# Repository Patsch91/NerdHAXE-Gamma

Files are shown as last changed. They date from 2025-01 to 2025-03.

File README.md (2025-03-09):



**The NerdHaxe-Gamma is a 6-Asic-Miner based on the [NerdQAxe+(+)](https://github.com/shufps/qaxe) / [Nerdaxe](https://github.com/BitMaker-hub/NerdAxeUltra) and inspired by [OSMU](https://osmu.wiki/) and the [Bitaxe](https://github.com/bitaxeorg)**

Current status: First version is running pretty solid. Disclaimer: This is a hobby project and not a professional or commercial product so feel free to build / make changes and share ideas on how to improve the design

 

# Specifications
- **Open Source:** All design files are provided, and suggestions/improvements are always welcome.
- **Standalone:** Using the T-Display S3 with WiFi and works without an external controller.
- **Performance:** ~7.35 TH/s average at around 120-125 watts (measured at the wall, including a MW UHP-200-12).
- **Case:** DIY Idea for a 3D-printed case with an integrated PSU.

# Software / Firmware
The NerdHaxe-Gamma uses the [ESP-Miner](https://github.com/shufps/ESP-Miner-NerdQAxePlus) by shufps and the [Webflasher](https://shufps.github.io/nerdqaxe-web-flasher/) is recommended as the easiest way to flash the NerdHaxe-Gamma (or any other Nerd*axe variant). It uses the official releases and is always up to date.
<br> The screen displays key values and parameters, such as the current hashrate, session runtime, fan speed, and more.
<br><br> 
<br> Via your browser, you can monitor all important aspects, such as the hashrate graph, adjust settings like core voltage and fan speed, define a fallback stratum pool, or simply check the logs.
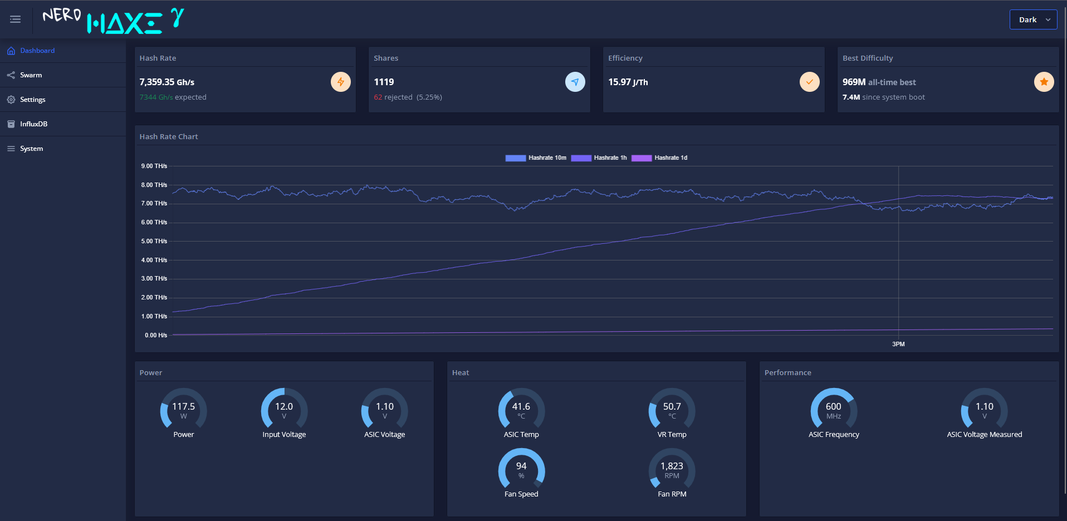
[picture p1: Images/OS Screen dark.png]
<br><br> 

# Components
- **Asics:** 6 x BM1370
- **T-Display S3:** ESP32S3 microcontroller with WiFi and integrated display
- **PCB:** I ordered the prototype PCB as specified in the KiCad files above, with a copper thickness of 1/1 oz, and it has been running well so far. One thing I tried on this PCB was exposing the pads underneath the ASICs to improve thermal connection to the backside of the PCB, where 10x10mm heatsinks can be placed.
- **BOM:** The board components needed for the build can be found in the BOM.
- **Heatsink:** The PCB has slotted holes that accommodate mounting patterns from 75x75mm to 80x80mm. The mounting patterns fit some LGA15xx or 2011 coolers, but be mindful of the thermal contact area of the coolers you want to use. Most standard coolers have a contact area of around 40x40mm, which is not sufficient. Therefore, I used server heatsinks such as the Supermicro SNK-P0048P(W) with a completely flat contact surface.
- **Fans:** Currently, I am using 2x Noctua A9x25 PWM chromax fans in a push-pull configuration, and at 75-85% PWM, the sound level is quite ok. I will soon test the Arctic P9 Max model, which is more powerful than the Noctuas, but of course, at a higher noise level.
- **PSU:** The NerdHaxe-Gamma operates at around 12V and 10A with default settings. Therefore, I recommend using a PSU that provides 12V and at least 15A. I am using the Meanwell UHP-200-12. <br>

# Misc 
**DISCLAIMER:** This device is an *advanced* build and partly WIP. To get 6 Asics soldered properly *can* be very hard and frustrating if you are not used to soldering Asics or soldering in general. Using that amount of power, this device is not a toy, and you should know what you are doing. Follow the regulations and precautions – **stay safe!** <br>

If you like this project and want to support future work, feel free to donate to: **`bc1q0ctaxeha3lpsaaz7kpjulflw2d9p66fhkp48dk`**

or related projects without which this project would not have been possible for me:

[NerdQAxe+](https://github.com/shufps/qaxe)

[OSMU](https://osmu.wiki/)

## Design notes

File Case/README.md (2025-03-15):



# Case 
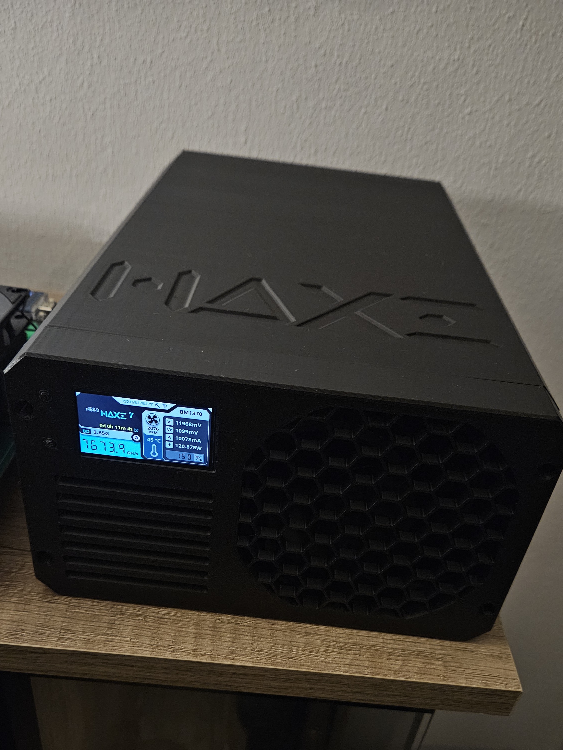
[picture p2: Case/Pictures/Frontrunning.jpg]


- **3D-printed parts:** You can find the files in here 
- **M3 inserts:** I used threaded nuts (M3) to hold the parts together 
- **PEM:** Power entry module with fuse and switch to cut the power without pulling any other connections. Please know what you are doing ad follow the regulations/rules as this is connected to AC.
- **Screws:** this design is made for M3 screws 
- **Fans:** I am using 2x Noctua A9x25 PWM chromax fans in a push-pull configuration, and at 80% PWM, the sound level is quite pleasant. The Arctic P9 Max are working very well with much headroom but at a higher noise level
- **PSU:** Meanwell UHP-200-12. <br>

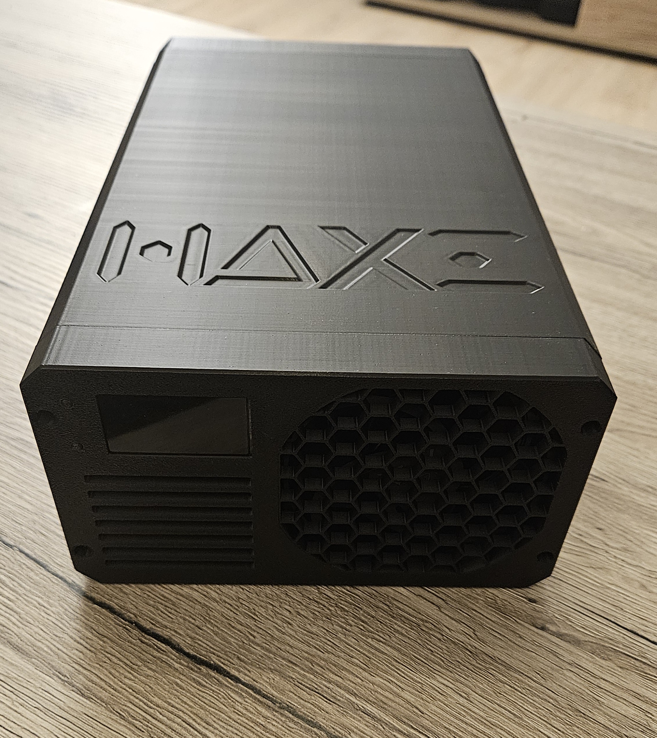
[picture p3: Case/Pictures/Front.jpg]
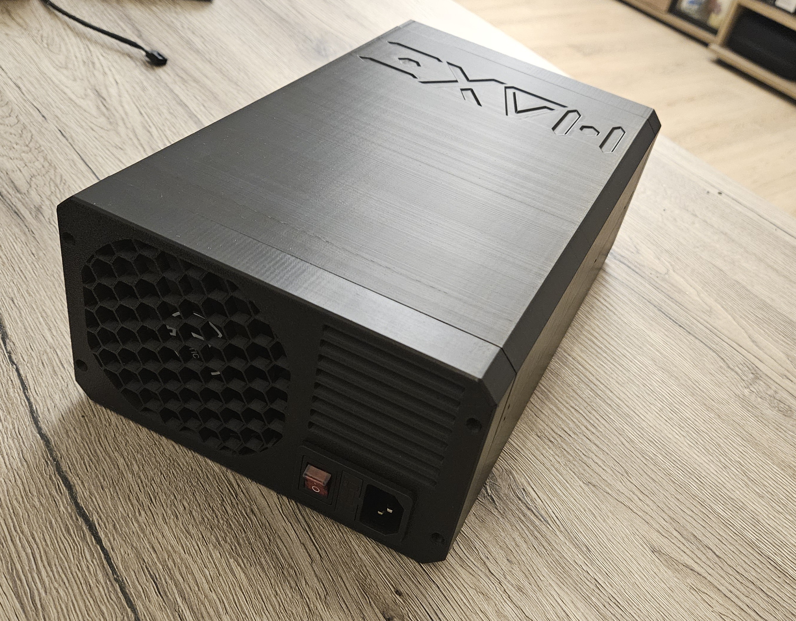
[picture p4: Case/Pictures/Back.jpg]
  

# Misc 
**DISCLAIMER:** This device is an *advanced* build and partly WIP. To get 6 Asics soldered properly *can* be very hard and frustrating if you are not used to soldering Asics or soldering in general. Using that amount of power, this device is not a toy, and you should know what you are doing. Follow the regulations and precautions – **stay safe!** <br>

If you like this project and want to support future work, feel free to donate to: **`bc1q0ctaxeha3lpsaaz7kpjulflw2d9p66fhkp48dk`**

or related projects without which this project would not have been possible for me:

[NerdQAxe+](https://github.com/shufps/qaxe)

[OSMU](https://osmu.wiki/)

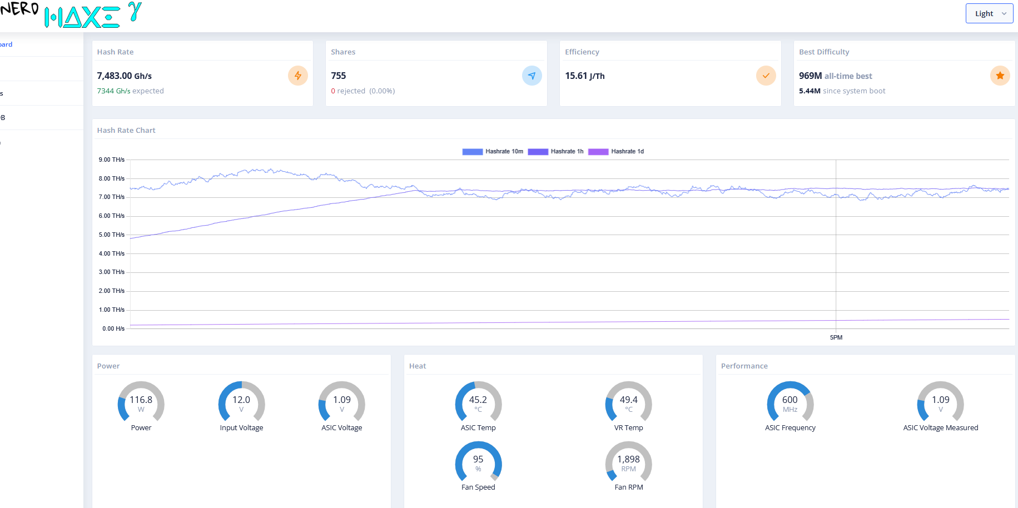
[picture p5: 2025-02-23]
Images/OS Screenshot light.png

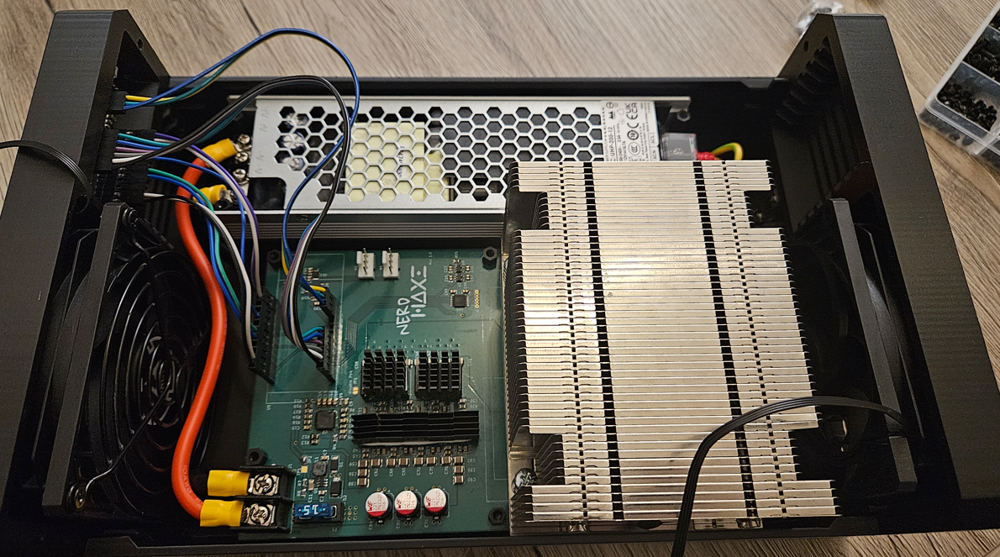
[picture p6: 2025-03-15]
Case/Pictures/Inside.png

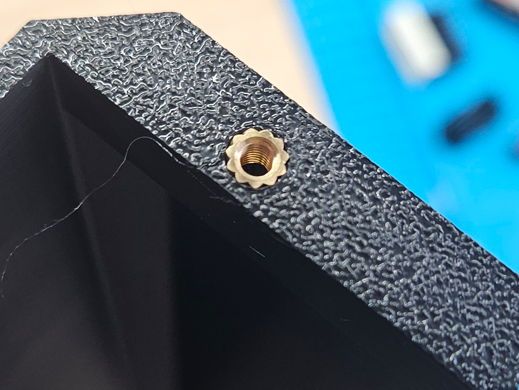
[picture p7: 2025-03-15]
Case/Pictures/Insert.png

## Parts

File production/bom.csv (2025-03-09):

Designator | Footprint | Quantity | Value | LCSC Part #
C1 | 0805 | 1 | 2.2n
C10 | 0805 | 1 | 330n
C100, C115, C127, C143, C159, C16, C175, C18, C19, C191, C20, C21, C23, C27, C28, C29, C30, C93, C94, C95, C96, C97, C98, C99 | 0805 | 24 | 100n/0.7mm
C101, C102, C103, C104, C105, C106, C107, C108, C109, C110, C111, C112, C114, C117, C118, C119, C12, C120, C121, C123, C125, C126, C128, C129, C130, C131, C132, C133, C134, C135, C136, C137, C139, C14, C141, C142, C144, C145, C146, C147, C148, C149, C150, C151, C152, C153, C155, C157, C158, C160, C161, C162, C163, C164, C165, C166, C167, C168, C169, C17, C171, C173, C174, C176, C177, C178, C179, C180, C181, C182, C183, C184, C185, C187, C189, C190, C192, C193, C194, C195, C196, C31, C43, C51, C57, C64 | 0805 | 86 | 1µ/25V
C11 | 1206 | 1 | 22µ/16V
C113, C122, C138, C154, C170, C186, C2, C41, C44, C46, C50 | 0805 | 11 | 10µ/25V
C116, C124, C140, C156, C172, C188, C42, C45, C48, C49, C52, C53, C55, C58 | 1210 | 14 | 100µ/6.3V
C13 | 0805 | 1 | 4.7µ
C15, C32, C33, C34, C35, C36, C37, C38, C39, C6, C9 | 0805 | 11 | 1n/0.7mm
C22, C24, C25, C26 | 0805 | 4 | 2.2µ
C3, C4, C5 | 0603 | 3 | 22p
C40, C47, C54, C61 | 0805 | 4 | 3.3n/25V
C56, C59, C62, C66, C69, C72, C75, C78, C82, C85, C88, C90 | 1210 | 12 | 22µ/25V
C60, C63, C65, C67, C68, C70, C71, C73, C74, C77, C79, C81, C83, C86, C87, C89, C91, C92 | 1210 | 18 | 330µ/4V
C7 | 0805 | 1 | 10n
C76, C80, C84 | CP_Elec_8x10 | 3 | 220µ/25V
C8 | 0603 | 1 | 12p
D1 | D_SOD-128 | 1 | PMEG4030EP,115
D2 | D_SMB | 1 | SMBJ12A
D3 | D_SOD-123 | 1 | 1N5819
F1 | Fuseholder Blade_3568 | 1 | 3568
J1 | CONN2 | 1 | Connector 02x01
L1 | L_Taiyo-Yuden_NR-50xx | 1 | 4.7µH/2.3A/2.7A
L2, L3, L4, L5 | IFLR-4031GC-01-8x10 | 4 | 220nH
M1, M2 | FanPinHeader_1x04_P2.54mm_Vertical | 2 | Fan_4pin
R1 | 0805 | 1 | 49.9k
R10, R11 | 0805 | 2 | 2.2R/0.5W
R12 | 0805 | 1 | 16.5k
R13 | 0805 | 1 | 24.3k
R14, R15, R16, R27, R31, R34, R37, R40, R43, R46, R48 | 0805 | 11 | 10k
R17, R18, R19, R20, R21, R22, R23, R24 | 0805 | 8 | 1R/0.5W
R2, R3 | 0805 | 2 | 100
R25, R26, R32, R35 | 0805 | 4 | 0
R28, R29 | 0805 | 2 | 2.7k
R30, R33, R36, R39, R42, R45 | 0805 | 6 | 1k
R4 | 0805 | 1 | 100k
R5 | 0805 | 1 | 121k
R6 | 0805 | 1 | 8.06k
R7 | 0805 | 1 | 84.5k
R8 | 0805 | 1 | 16.2k
R9 | 0805 | 1 | 2.55k
U1 | SOT-23-6 | 1 | AP3211
U10 | MSOP-10_3x3mm_P0.5mm | 1 | EMC2302-1
U11 | VSSOP-8_2.3x2mm_P0.5mm | 1 | TXU0102-DCU
U12, U13 | TMP1075-DRL | 2 | TMP1075
U14 | TSSOP-14-1EP_4.4x5mm_P0.65mm | 1 | TXU0304PW
U15 | Oscillator_SMD_EuroQuartz_XO32-4Pin_3.2x2.5mm | 1 | 25MHz
U16, U17, U18, U19, U20, U21 | BM1370 | 6 | BM1370_mode1
U2 | Texas_RHA0040B_VQFN-40-1EP_6x6mm_P0.5mm_EP4.15x4.15mm_ThermalVias | 1 | TPS53647
U3 | SOT-23-5 | 1 | MCP1824T-0802E
U4, U5, U6, U7 | CSD95472-SON-5x6 | 4 | CSD95472Q5MC
U8 | SOT-23-5 | 1 | MCP1824T-1202E

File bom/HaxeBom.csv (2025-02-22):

Reference | Value | Footprint | OrderNr | Qty | DNP | Distributor
C1 | 2.2n | Capacitor_SMD:C_0805_2012Metric | 1276-2993-1-ND | 1 |  | D
C2,C41,C44,C46,C50,C113,C122,C138,C154,C170,C186 | 10µ/25V | Capacitor_SMD:C_0805_2012Metric | 445-5984-1-ND | 11 |  | D
C3,C4,C5 | 22p | Capacitor_SMD:C_0603_1608Metric | 478-KGM15ACG1H220JTCT-ND | 3 |  | D
C6,C9,C15,C32,C33,C34,C35,C36,C37,C38,C39 | 1n/0.7mm | Capacitor_SMD:C_0805_2012Metric | 311-1472-1-ND | 11 |  | D
C7 | 10n | Capacitor_SMD:C_0805_2012Metric | 732-8021-1-ND | 1 |  | D
C8 | 12p | Capacitor_SMD:C_0603_1608Metric | 478-KGM15ACG2A120JMCT-ND | 1 |  | D
C10 | 330n | Capacitor_SMD:C_0805_2012Metric | 399-C0805C334K3RECAUTOCT-ND | 1 |  | D
C11 | 22µ/16V | Capacitor_SMD:C_1206_3216Metric | 1276-2728-1-ND | 1 |  | D
C12,C14,C17,C31,C43,C51,C57,C64,C101,C102,C103,C104,C105,C106,C107,C108,C109,C110,C111,C112,C114,C117,C118,C119,C120,C121,C123,C125,C126,C128,C129,C130,C131,C132,C133,C134,C135,C136,C137,C139,C141,C142,C144,C145,C146,C147,C148,C149,C150,C151,C152,C153,C155,C157,C158,C160,C161,C162,C163,C164,C165,C166,C167,C168,C169,C171,C173,C174,C176,C177,C178,C179,C180,C181,C182,C183,C184,C185,C187,C189,C190,C192,C193,C194,C195,C196 | 1µ/25V | Capacitor_SMD:C_0805_2012Metric | 1276-1066-1-ND | 86 |  | D
C13 | 4.7µ | Capacitor_SMD:C_0805_2012Metric | 1276-1244-1-ND | 1 |  | D
C16,C18,C19,C20,C21,C23,C27,C28,C29,C30,C93,C94,C95,C96,C97,C98,C99,C100,C115,C127,C143,C159,C175,C191 | 100n/0.7mm | Capacitor_SMD:C_0805_2012Metric | 311-3037-1-ND | 24 |  | D
C22,C24,C25,C26 | 2.2µ | Capacitor_SMD:C_0805_2012Metric | 1276-6458-1-ND | 4 |  | D
C40,C47,C54,C61 | 3.3n/25V | Capacitor_SMD:C_0805_2012Metric | 490-8291-1-ND | 4 |  | D
C42,C45,C48,C49,C52,C53,C55,C58,C116,C124,C140,C156,C172,C188 | 100µ/6.3V | Capacitor_SMD:C_1210_3225Metric | 399-C1210C107M8PAC7800CT-ND | 14 |  | D
C56,C59,C62,C66,C69,C72,C75,C78,C82,C85,C88,C90 | 22µ/25V | Capacitor_SMD:C_1210_3225Metric | 399-C1210C226K3PAC7800CT-ND | 12 |  | D
C60,C63,C65,C67,C68,C70,C71,C73,C74,C77,C79,C81,C83,C86,C87,C89,C91,C92 | 330µ/4V | Capacitor_SMD:C_1210_3225Metric | 490-GRM32ER60G337ME05KCT-ND | 18 |  | D
C76,C80,C84 | 220µ/25V | Capacitor_SMD:CP_Elec_8x10 | 732-6489-1-ND | 3 |  | D
D1 | PMEG4030EP,115 | Diode_SMD:D_SOD-128 | 1727-5841-1-ND | 1 |  | D
D2 | SMBJ12A | Diode_SMD:D_SMB | SMBJ12ALFCT-ND | 1 |  | D
D3 | 1N5819 | Diode_SMD:D_SOD-123 | 31-1N5819HWQ-7-FCT-ND | 1 |  | D
F1 | 3568 | 8Axe:Fuseholder Blade_3568 | 36-3568-ND | 1 |  | D
H1 | Threaded Inserts |  | 36-24949CT-ND | 1 |  | D
J1 | Connector 02x01 | Nerd8:CONN2 | ED2953-ND | 1 |  | D
J4,J5 | Conn_01x12-Socket |  | 732-61301211821-ND | 2 |  | D
J6,J7 | Conn_01x12-Header |  | 2057-PH1-12-UA-ND | 2 |  | D
L1 | 4.7µH/2.3A/2.7A | Inductor_SMD:L_Taiyo-Yuden_NR-50xx | 732-7244-1-ND | 1 |  | D
L2,L3,L4,L5 | 220nH | myfootprints:IFLR-4031GC-01-8x10 | 283-FP1008R5-R220-RCT-ND | 4 |  | D
M1,M2 | Fan_4pin | Connector:FanPinHeader_1x04_P2.54mm_Vertical | WM4330-ND | 2 |  | D
R1 | 49.9k | Resistor_SMD:R_0805_2012Metric | 311-49.9KCRCT-ND | 1 |  | D
R2,R3 | 100 | Resistor_SMD:R_0805_2012Metric | 311-100CRCT-ND | 2 |  | D
R4 | 100k | Resistor_SMD:R_0805_2012Metric | RMCF0805FT100KCT-ND | 1 |  | D
R5 | 121k | Resistor_SMD:R_0805_2012Metric | RMCF0805FT121KCT-ND | 1 |  | D
R6 | 8.06k | Resistor_SMD:R_0805_2012Metric | RMCF0805FT8K06CT-ND | 1 |  | D
R7 | 84.5k | Resistor_SMD:R_0805_2012Metric | 311-84.5KCRCT-ND | 1 |  | D
R8 | 16.2k | Resistor_SMD:R_0805_2012Metric | RMCF0805FT16K2CT-ND | 1 |  | D
R9 | 2.55k | Resistor_SMD:R_0805_2012Metric | 311-2.55KCRCT-ND | 1 |  | D
R10,R11 | 2.2R/0.5W | Resistor_SMD:R_0805_2012Metric | 541-10524-1-ND | 2 |  | D
R12 | 16.5k | Resistor_SMD:R_0805_2012Metric | 541-16.5KCCT-ND | 1 |  | D
R13 | 24.3k | Resistor_SMD:R_0805_2012Metric | 311-24.3KCRCT-ND | 1 |  | D
R14,R15,R16,R27,R31,R34,R37,R40,R43,R46,R48 | 10k | Resistor_SMD:R_0805_2012Metric | RMCF0805FT10K0CT-ND | 11 |  | D
R17,R18,R19,R20,R21,R22,R23,R24 | 1R/0.5W | Resistor_SMD:R_0805_2012Metric | 541-1.00TCT-ND | 8 |  | D
R25,R26,R32,R35 | 0 | Resistor_SMD:R_0805_2012Metric | RMCF0805ZT0R00CT-ND | 4 |  | D
R28,R29 | 2.7k | Resistor_SMD:R_0805_2012Metric | RMCF0805FT2K70CT-ND | 2 |  | D
R30,R33,R36,R39,R42,R45 | 1k | Resistor_SMD:R_0805_2012Metric | RNCP0805FTD1K00CT-ND | 6 |  | D
U1 | AP3211 | Package_TO_SOT_SMD:SOT-23-6 | AP3211KTR-G1DICT-ND | 1 |  | D
U2 | TPS53647 | Package_DFN_QFN:Texas_RHA0040B_VQFN-40-1EP_6x6mm_P0.5mm_EP4.15x4.15mm_ThermalVias | 296-51986-1-ND | 1 |  | D
U3 | MCP1824T-0802E | Package_TO_SOT_SMD:SOT-23-5 | MCP1824T-0802E/OTCT-ND | 1 |  | D
U4,U5,U6,U7 | CSD95472Q5MC | myfootprints:CSD95472-SON-5x6 | 296-43950-1-ND | 4 |  | D
U8 | MCP1824T-1202E | Package_TO_SOT_SMD:SOT-23-5 | MCP1824T-1202E/OTCT-ND | 1 |  | D
U9 | T-Display-S3 | myfootprints:T-Display-S3 |  | 1 | Nicht bestücken
U10 | EMC2302-1 | Package_SO:MSOP-10_3x3mm_P0.5mm | EMC2302-1-AIZL-CT-ND | 1 |  | D
U11 | TXU0102-DCU | Package_SO:VSSOP-8_2.3x2mm_P0.5mm | 296-TXU0102DCURCT-ND | 1 |  | D
U12,U13 | TMP1075 | Qaxe:TMP1075-DRL | 296-TMP1075NDRLRCT-ND | 2 |  | D
U14 | TXU0304PW | Package_SO:TSSOP-14-1EP_4.4x5mm_P0.65mm | 296-TXU0304PWRCT-ND | 1 |  | D
U15 | 25MHz | Oscillator:Oscillator_SMD_EuroQuartz_XO32-4Pin_3.2x2.5mm | 1923-1664-1-ND | 1 |  | D
U16,U17,U18,U19,U20,U21 | BM1370_mode1 | Nerd8:BM1370 |  | 6

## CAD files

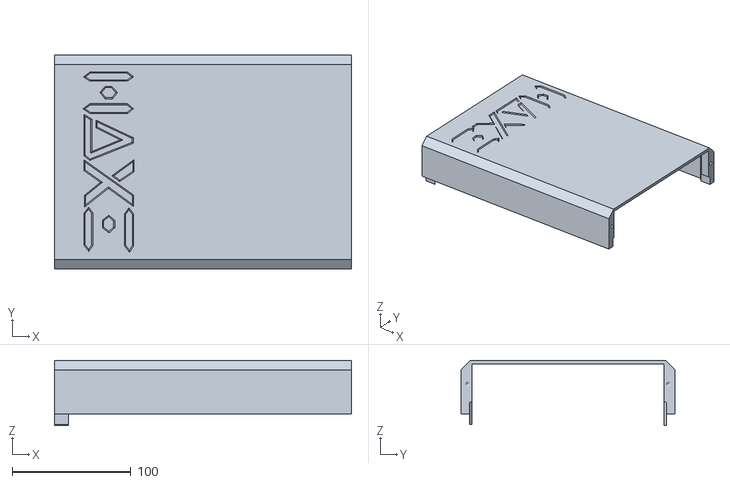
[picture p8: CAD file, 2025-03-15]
Case/Top-Body.stl
250.0 x 180.0 x 55.0

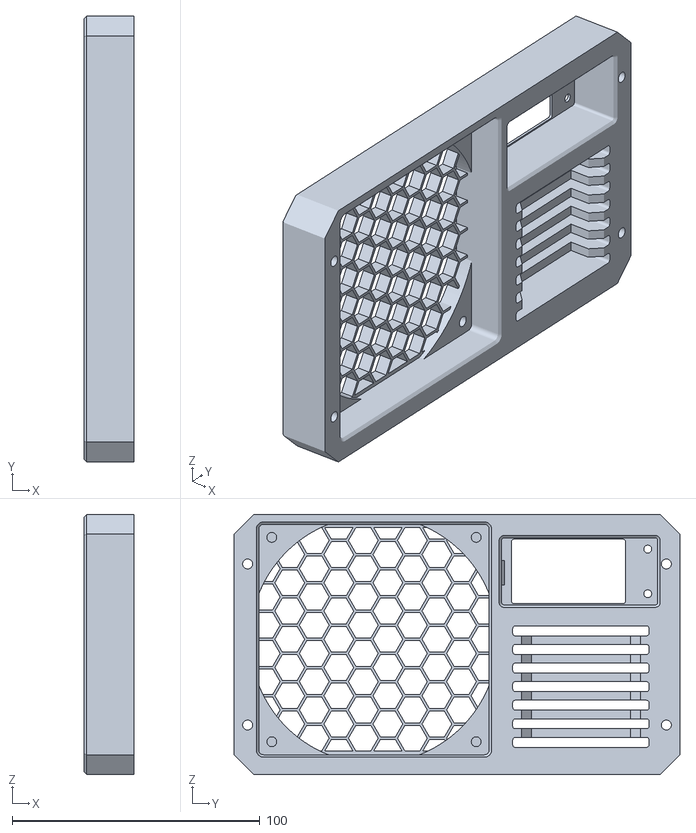
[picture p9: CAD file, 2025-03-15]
Case/Front-Body.stl
20.0 x 180.0 x 105.0

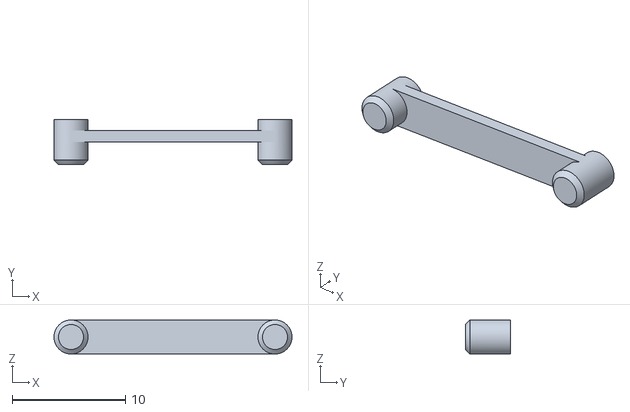
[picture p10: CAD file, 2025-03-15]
Case/Buttons-Body.stl
21.0 x 4.00 x 3.00

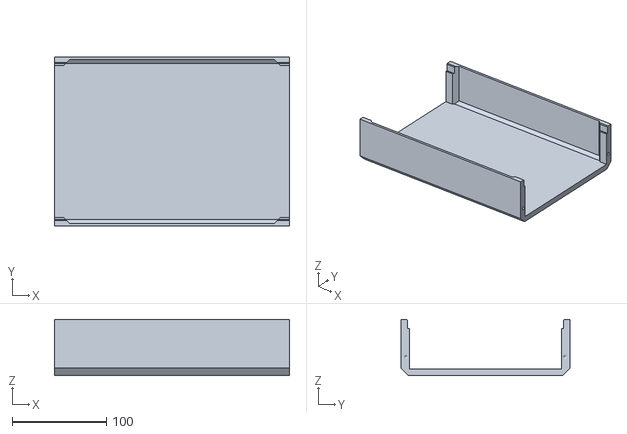
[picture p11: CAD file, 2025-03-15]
Case/Boden-Body.stl
250.0 x 180.0 x 60.0

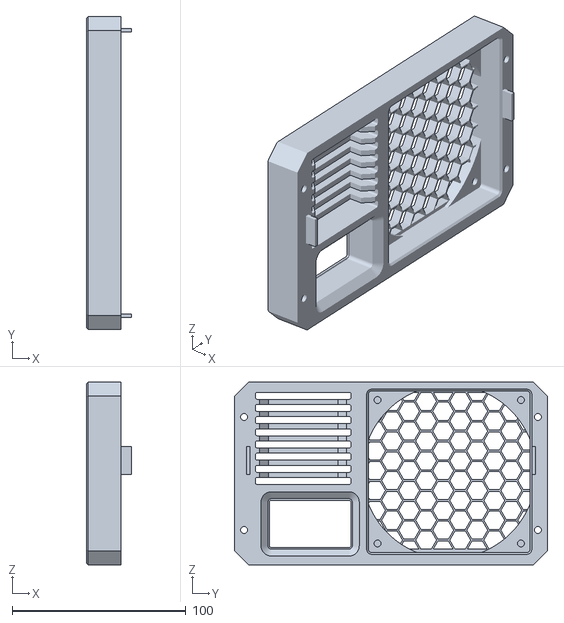
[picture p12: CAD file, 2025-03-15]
Case/Back-Body.stl
26.0 x 180.0 x 105.0

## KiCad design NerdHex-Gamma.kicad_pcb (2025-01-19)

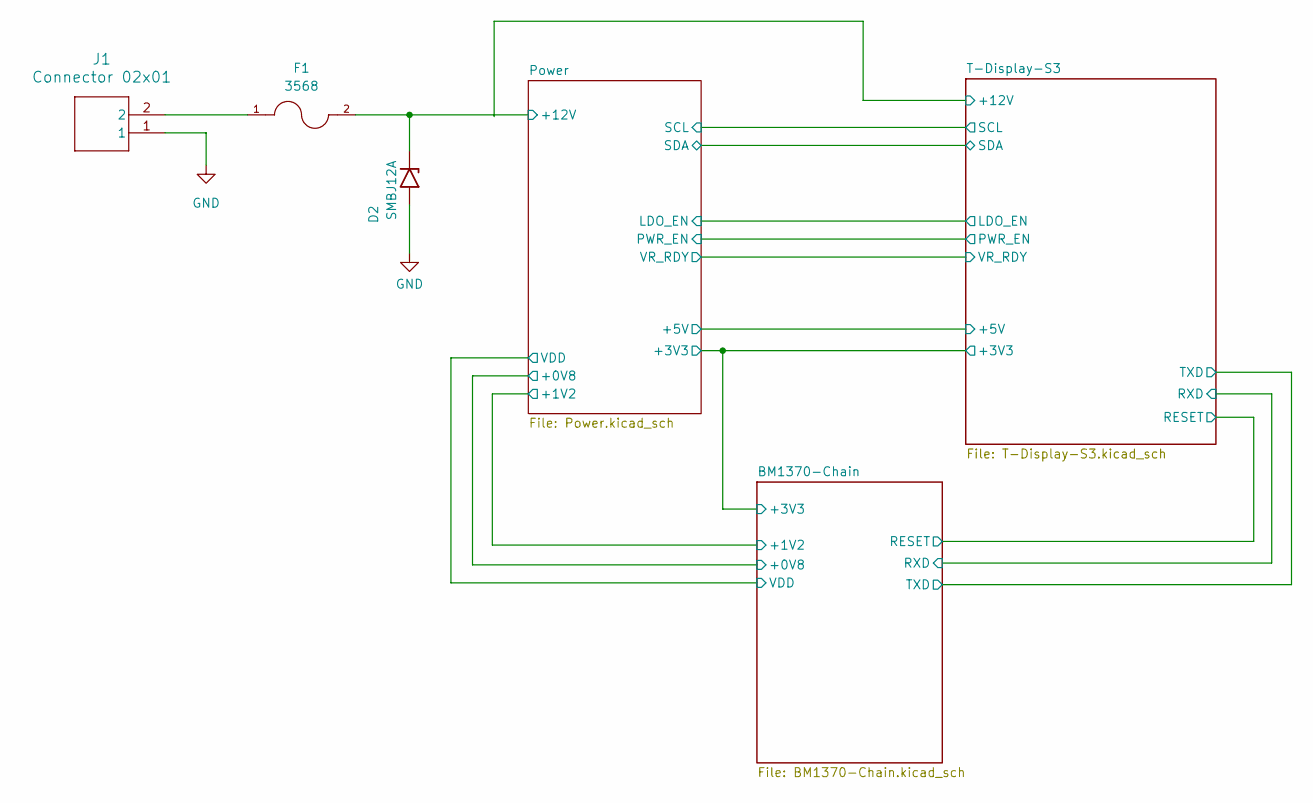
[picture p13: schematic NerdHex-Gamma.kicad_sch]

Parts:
D2: SMBJ12A; D_SMB
F1: 3568; Fuseholder Blade_3568
J1: Connector 02x01; CONN2

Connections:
+12V: D2.1 (A1), F1.2, F1.4; also elsewhere on the board
GND: D2.2 (A2), J1.1; also elsewhere on the board
unnamed: F1.1, F1.3, J1.2

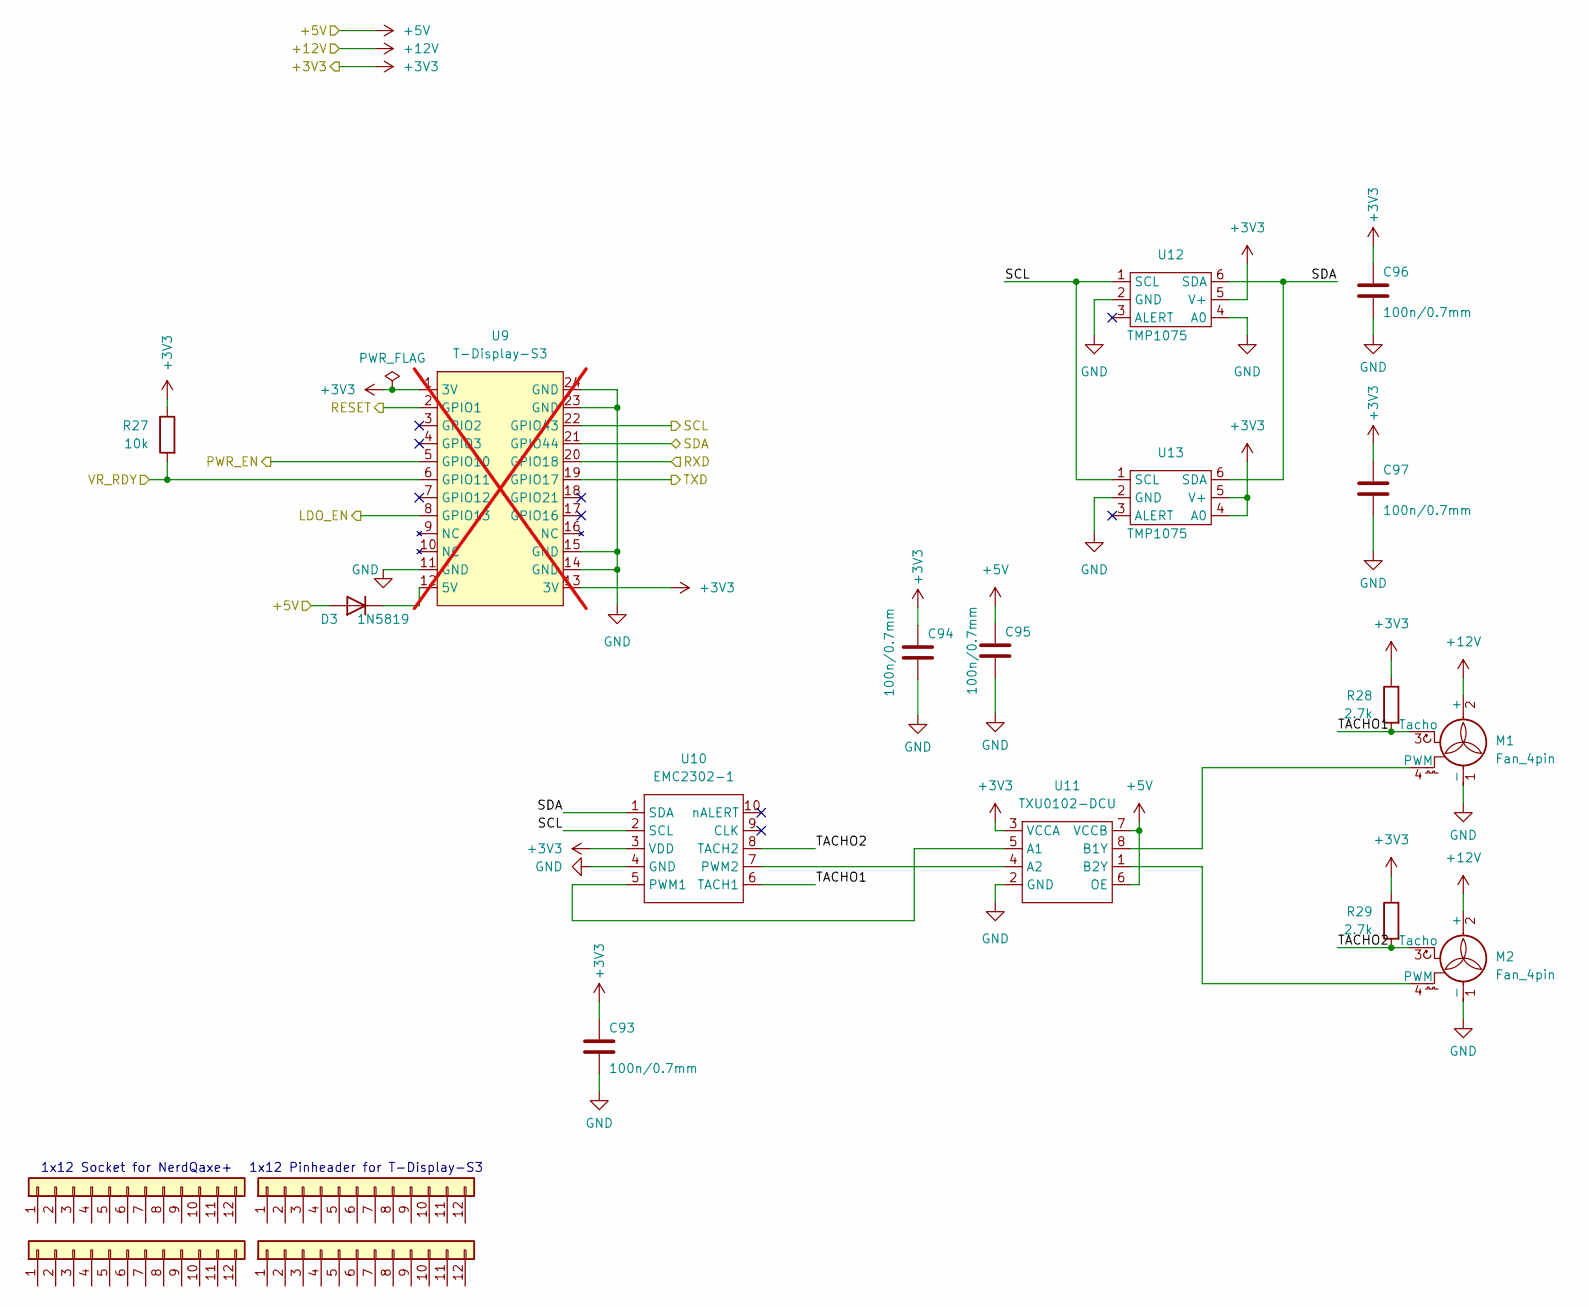
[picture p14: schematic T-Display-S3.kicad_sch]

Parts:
C93, C94, C95, C96, C97: 100n/0.7mm; C_0805_2012Metric
D3: 1N5819; D_SOD-123
J4, J5: Conn_01x12-Socket
J6, J7: Conn_01x12-Header
M1, M2: Fan_4pin; FanPinHeader_1x04_P2.54mm_Vertical
R27: 10k; R_0805_2012Metric
R28, R29: 2.7k; R_0805_2012Metric
U9: T-Display-S3; not fitted
U10: EMC2302-1; MSOP-10_3x3mm_P0.5mm
U11: TXU0102-DCU; VSSOP-8_2.3x2mm_P0.5mm
U12, U13: TMP1075; TMP1075-DRL

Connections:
+3V3: C93.1, C94.1, C96.1, C97.1, R27.1, R28.1, R29.1, U9.1 (3V), U9.13 (3V), U10.3 (VDD), U11.3 (VCCA), U12.5 (V+), U13.4 (A0), U13.5 (V+); also elsewhere on the board
+5V: C95.1, D3.2 (A), U11.6 (OE), U11.7 (VCCB); also elsewhere on the board
+12V: M1.2 (+), M2.2 (+); also elsewhere on the board
/BM1370-Chain/RESET: U9.2 (GPIO1); also elsewhere on the board
/BM1370-Chain/RXD: U9.20 (GPIO18); also elsewhere on the board
/BM1370-Chain/TXD: U9.19 (GPIO17); also elsewhere on the board
/Power/LDO_EN: U9.8 (GPIO13); also elsewhere on the board
/Power/PWR_EN: U9.5 (GPIO10); also elsewhere on the board
/Power/VR_RDY: R27.2, U9.6 (GPIO11); also elsewhere on the board
/T-Display-S3/SCL: U9.22 (GPIO43), U10.2 (SCL), U12.1 (SCL), U13.1 (SCL); also elsewhere on the board
/T-Display-S3/SDA: U9.21 (GPIO44), U10.1 (SDA), U12.6 (SDA), U13.6 (SDA); also elsewhere on the board
/T-Display-S3/TACHO1: M1.3 (Tacho), R28.2, U10.6 (TACH1)
/T-Display-S3/TACHO2: M2.3 (Tacho), R29.2, U10.8 (TACH2)
GND: C93.2, C94.2, C95.2, C96.2, C97.2, M1.1 (-), M2.1 (-), U9.11 (GND), U9.14 (GND), U9.15 (GND), U9.23 (GND), U9.24 (GND), U10.4 (GND), U11.2 (GND), U12.2 (GND), U12.4 (A0), U13.2 (GND); also elsewhere on the board
unnamed: D3.1 (K), U9.12 (5V)
unnamed: M1.4 (PWM), U11.8 (B1Y)
unnamed: M2.4 (PWM), U11.1 (B2Y)
unnamed: U10.5 (PWM1), U11.5 (A1)
unnamed: U10.7 (PWM2), U11.4 (A2)

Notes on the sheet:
1x12 Socket for NerdQaxe+
1x12 Pinheader for T-Display-S3

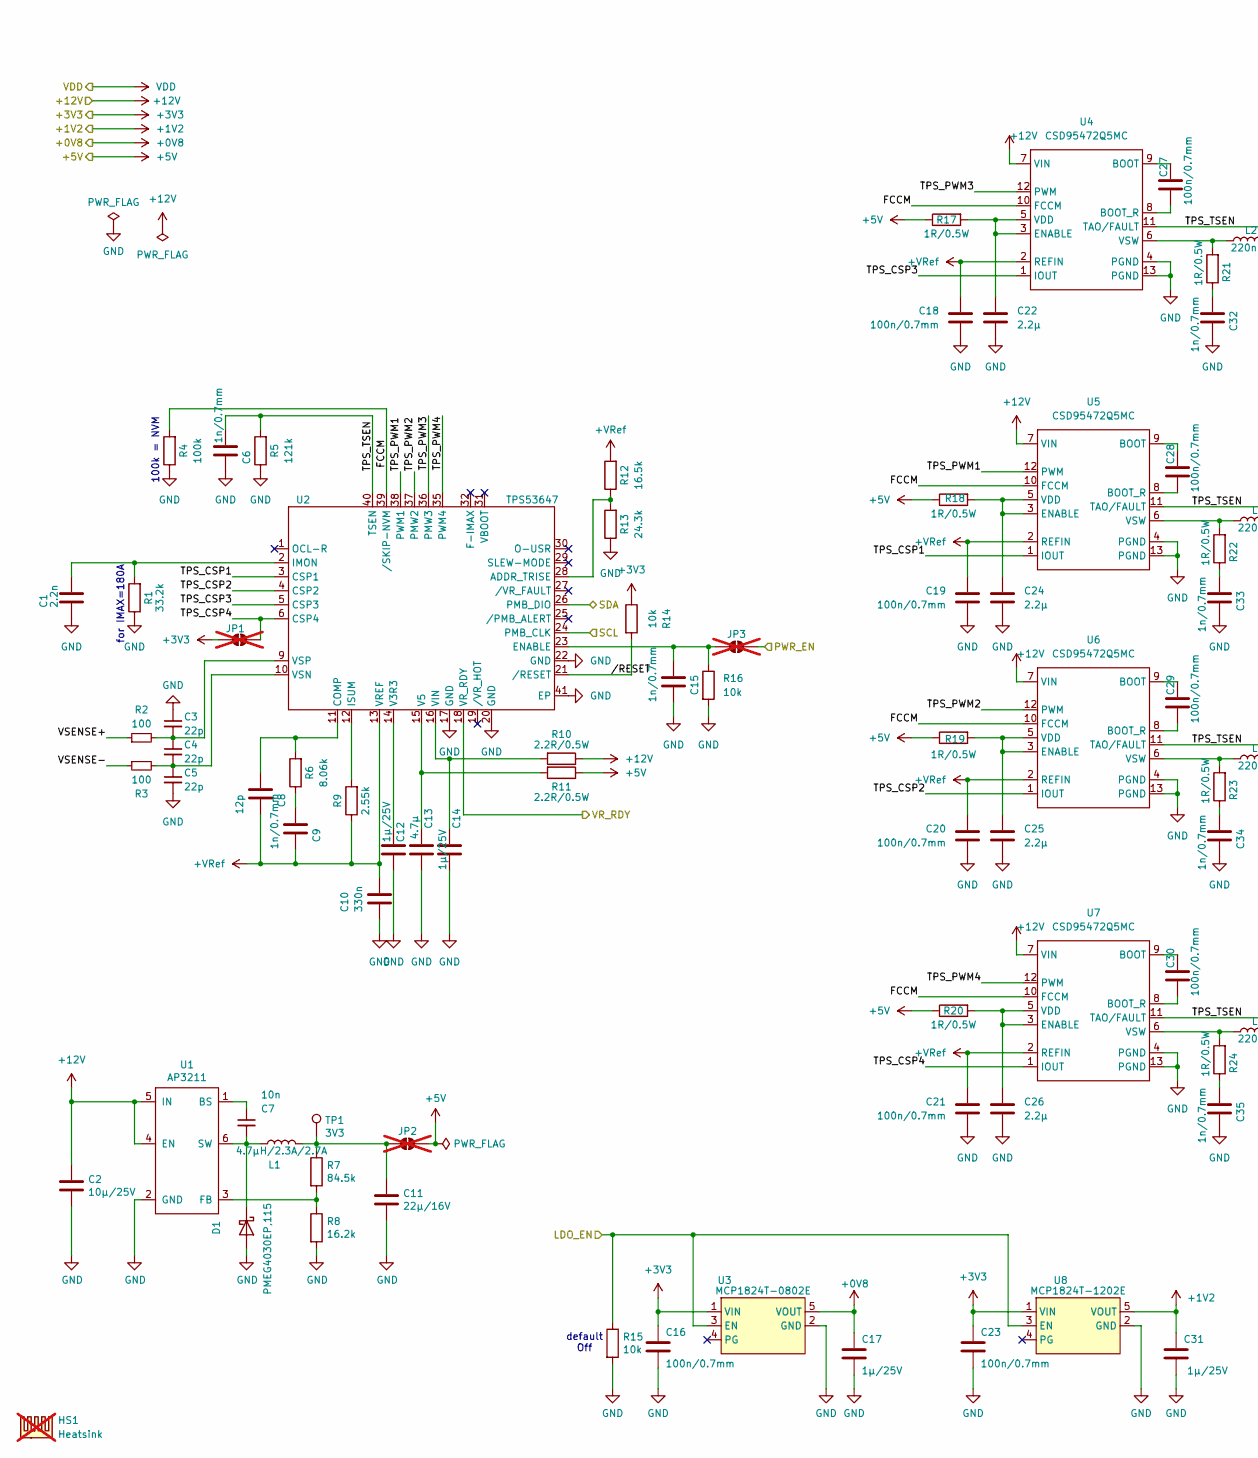
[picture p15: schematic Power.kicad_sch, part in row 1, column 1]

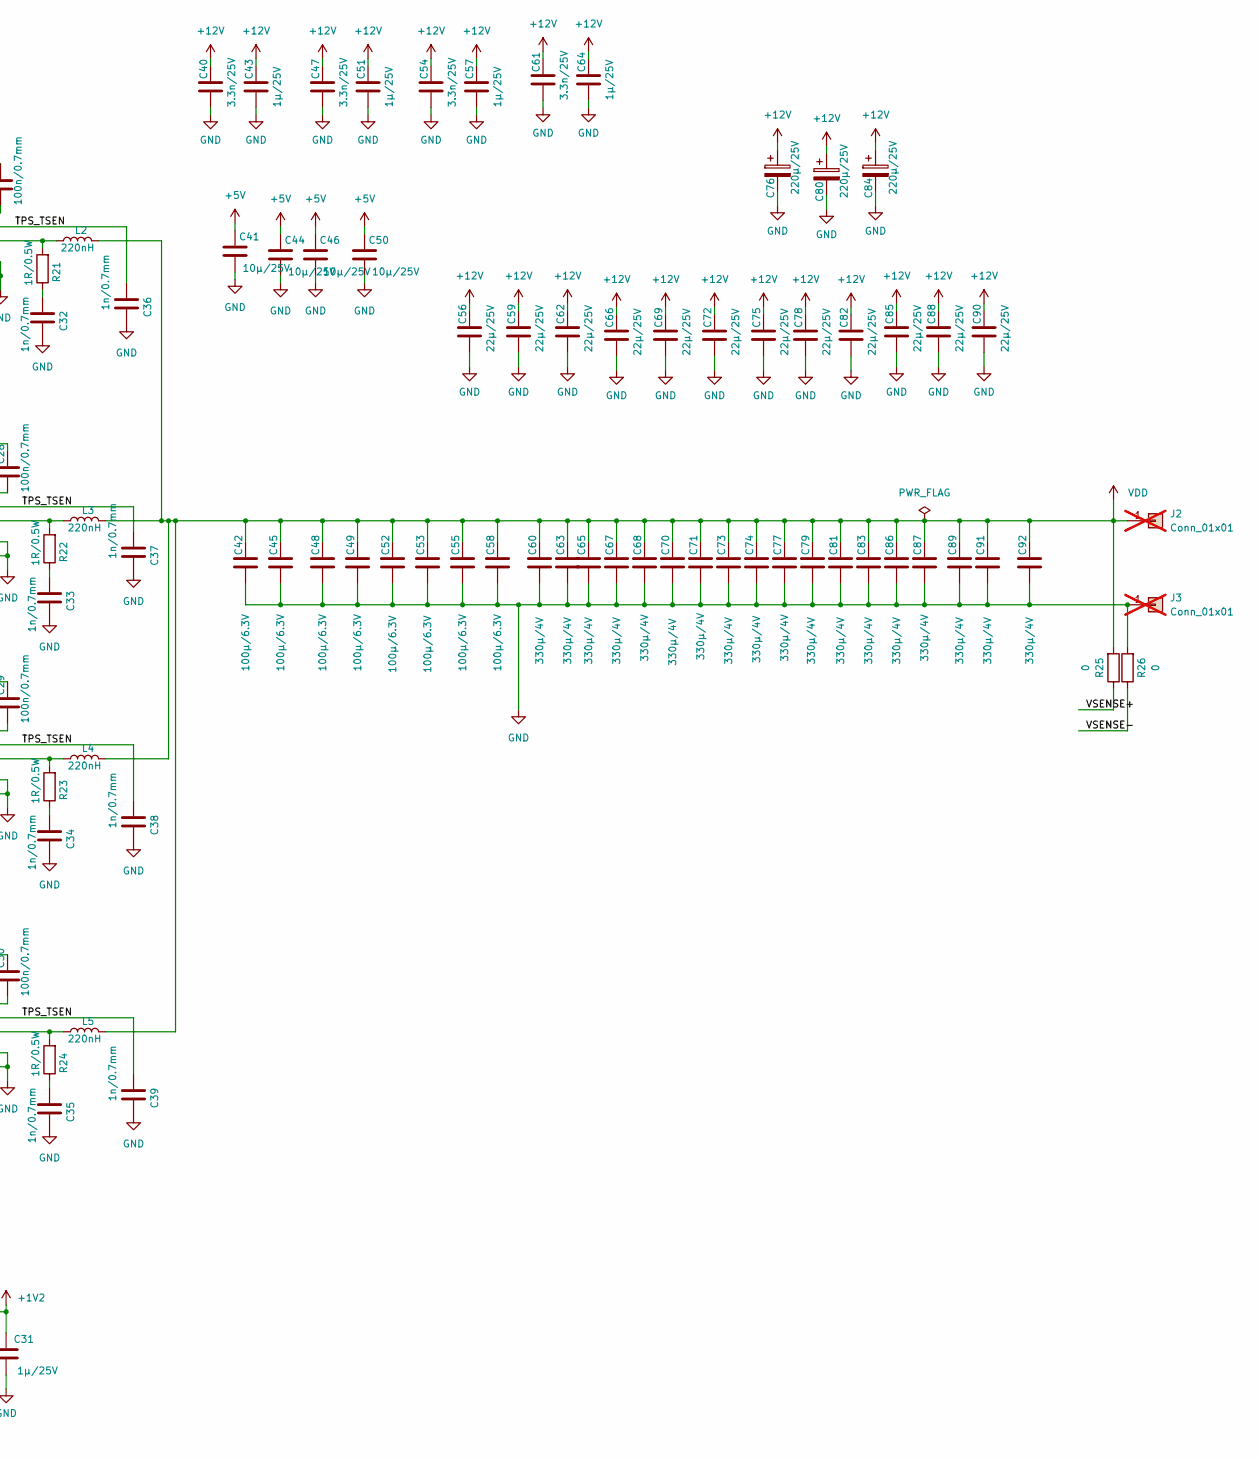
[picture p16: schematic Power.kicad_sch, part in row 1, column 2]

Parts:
C1: 2.2n; C_0805_2012Metric
C2, C41, C44, C46, C50: 10µ/25V; C_0805_2012Metric
C3, C4, C5: 22p; C_0603_1608Metric
C6, C9, C15, C32, C33, C34, C35, C36, C37, C38, C39: 1n/0.7mm; C_0805_2012Metric
C7: 10n; C_0805_2012Metric
C8: 12p; C_0603_1608Metric
C10: 330n; C_0805_2012Metric
C11: 22µ/16V; C_1206_3216Metric
C12, C14, C17, C31, C43, C51, C57, C64: 1µ/25V; C_0805_2012Metric
C13: 4.7µ; C_0805_2012Metric
C16, C18, C19, C20, C21, C23, C27, C28, C29, C30: 100n/0.7mm; C_0805_2012Metric
C22, C24, C25, C26: 2.2µ; C_0805_2012Metric
C40, C47, C54, C61: 3.3n/25V; C_0805_2012Metric
C42, C45, C48, C49, C52, C53, C55, C58: 100µ/6.3V; C_1210_3225Metric
C56, C59, C62, C66, C69, C72, C75, C78, C82, C85, C88, C90: 22µ/25V; C_1210_3225Metric
C60, C63, C65, C67, C68, C70, C71, C73, C74, C77, C79, C81, C83, C86, C87, C89, C91, C92: 330µ/4V; C_1210_3225Metric
C76, C80, C84: 220µ/25V; CP_Elec_8x10
D1: PMEG4030EP,115; D_SOD-128
HS1: Heatsink; not fitted
J2, J3: Conn_01x01; Wuerth_REDCUBE-THR_WP-THRBU_74650194_THR; not fitted
JP1: Disable Phase 4; SolderJumper-2_P1.3mm_Open_RoundedPad1.0x1.5mm; not fitted
JP2, JP3: SolderJumper_2_Open; SolderJumper-2_P1.3mm_Open_RoundedPad1.0x1.5mm; not fitted
L1: 4.7µH/2.3A/2.7A; L_Taiyo-Yuden_NR-50xx
L2, L3, L4, L5: 220nH; IFLR-4031GC-01-8x10
R1: 33.2k; R_0805_2012Metric
R2, R3: 100; R_0805_2012Metric
R4: 100k; R_0805_2012Metric
R5: 121k; R_0805_2012Metric
R6: 8.06k; R_0805_2012Metric
R7: 84.5k; R_0805_2012Metric
R8: 16.2k; R_0805_2012Metric
R9: 2.55k; R_0805_2012Metric
R10, R11: 2.2R/0.5W; R_0805_2012Metric
R12: 16.5k; R_0805_2012Metric
R13: 24.3k; R_0805_2012Metric
R14, R15, R16: 10k; R_0805_2012Metric
R17, R18, R19, R20, R21, R22, R23, R24: 1R/0.5W; R_0805_2012Metric
R25, R26: 0; R_0805_2012Metric
TP1: 3V3; TestPoint_Pad_2.0x2.0mm
U1: AP3211; SOT-23-6
U2: TPS53647; Texas_RHA0040B_VQFN-40-1EP_6x6mm_P0.5mm_EP4.15x4.15mm_Therm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
U3: MCP1824T-0802E; SOT-23-5
U4, U5, U6, U7: CSD95472Q5MC; CSD95472-SON-5x6
U8: MCP1824T-1202E; SOT-23-5

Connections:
+0V8: C17.1, U3.5 (VOUT); also elsewhere on the board
+1V2: C31.1, U8.5 (VOUT); also elsewhere on the board
+3V3: C16.1, C23.1, JP1.1 (A), R14.1, U3.1 (VIN), U8.1 (VIN); also elsewhere on the board
+5V: C41.1, C44.1, C46.1, C50.1, JP2.2 (B), R11.1, R17.1, R18.1, R19.1, R20.1; also elsewhere on the board
+12V: C2.1, C40.1, C43.1, C47.1, C51.1, C54.1, C56.1, C57.1, C59.1, C61.1, C62.1, C64.1, C66.1, C69.1, C72.1, C75.1, C76.1, C78.1, C80.1, C82.1, C84.1, C85.1, C88.1, C90.1, R10.1, U1.4 (EN), U1.5 (IN), U4.7 (VIN), U5.7 (VIN), U6.7 (VIN), U7.7 (VIN); also elsewhere on the board
+VRef: C8.2, C9.2, C10.1, C18.1, C19.1, C20.1, C21.1, R9.1, R12.2, U2.13 (VREF), U4.2 (REFIN), U5.2 (REFIN), U6.2 (REFIN), U7.2 (REFIN)
/Power/FCCM: R4.2, U2.39 (/SKIP-NVM), U4.10 (FCCM), U5.10 (FCCM), U6.10 (FCCM), U7.10 (FCCM)
/Power/LDO_EN: R15.1, U3.3 (EN), U8.3 (EN); also elsewhere on the board
/Power/PWR_EN: JP3.2 (B); also elsewhere on the board
/Power/TPS_CSP1: U2.3 (CSP1), U5.1 (IOUT)
/Power/TPS_CSP2: U2.4 (CSP2), U6.1 (IOUT)
/Power/TPS_CSP3: U2.5 (CSP3), U4.1 (IOUT)
/Power/TPS_CSP4: JP1.2 (B), U2.6 (CSP4), U7.1 (IOUT)
/Power/TPS_PWM1: U2.38 (PWM1), U5.12 (PWM)
/Power/TPS_PWM2: U2.37 (PMW2), U6.12 (PWM)
/Power/TPS_PWM3: U2.36 (PMW3), U4.12 (PWM)
/Power/TPS_PWM4: U2.35 (PWM4), U7.12 (PWM)
/Power/TPS_TSEN: C6.1, C36.1, C37.1, C38.1, C39.1, R5.2, U2.40 (TSEN), U4.11 (TAO/FAULT), U5.11 (TAO/FAULT), U6.11 (TAO/FAULT), U7.11 (TAO/FAULT)
/Power/VR_RDY: U2.18 (VR_RDY); also elsewhere on the board
/Power/VSENSE+: R2.1, R25.1
/Power/VSENSE-: R3.1, R26.1
/Power//RESET: R14.2, U2.21 (/RESET)
/T-Display-S3/SCL: U2.24 (PMB_CLK); also elsewhere on the board
/T-Display-S3/SDA: U2.26 (PMB_DIO); also elsewhere on the board
GND: C1.2, C2.2, C3.1, C5.2, C6.2, C10.2, C11.2, C12.2, C13.1, C14.1, C15.2, C16.2, C17.2, C18.2, C19.2, C20.2, C21.2, C22.2, C23.2, C24.2, C25.2, C26.2, C31.2, C32.2, C33.2, C34.2, C35.2, C36.2, C37.2, C38.2, C39.2, C40.2, C41.2, C42.2, C43.2, C44.2, C45.2, C46.2, C47.2, C48.2, C49.2, C50.2, C51.2, C52.2, C53.2, C54.2, C55.2, C56.2, C57.2, C58.2, C59.2, C60.2, C61.2, C62.2, C63.2, C64.2, C65.2, C66.2, C67.2, C68.2, C69.2, C70.2, C71.2, C72.2, C73.2, C74.2, C75.2, C76.2, C77.2, C78.2, C79.2, C80.2, C81.2, C82.2, C83.2, C84.2, C85.2, C86.2, C87.2, C88.2, C89.2, C90.2, C91.2, C92.2, D1.2 (A), J3.1, R1.1, R4.1, R5.1, R8.2, R13.1, R15.2, R16.2, R26.2, U1.2 (GND), U2.17 (GND), U2.20 (GND), U2.22 (GND), U2.41 (EP), U3.2 (GND), U4.4 (PGND), U4.13 (PGND), U5.4 (PGND), U5.13 (PGND), U6.4 (PGND), U6.13 (PGND), U7.4 (PGND), U7.13 (PGND), U8.2 (GND); also elsewhere on the board
unnamed: C9.1, R6.1
unnamed: C32.1, R21.1
unnamed: C33.1, R22.1
unnamed: C34.1, R23.1
unnamed: C35.1, R24.1
unnamed: C7.2, D1.1 (K), L1.1, U1.6 (SW)
unnamed: C11.1, JP2.1 (A), L1.2, R7.1, TP1.1
unnamed: C15.1, JP3.1 (A), R16.1, U2.23 (ENABLE)
unnamed: C7.1, U1.1 (BS)
unnamed: R7.2, R8.1, U1.3 (FB)
unnamed: R12.1, R13.2, U2.28 (ADDR_TRISE)
unnamed: C8.1, R6.2, U2.11 (COMP)
unnamed: C1.1, R1.2, U2.2 (IMON)
unnamed: R9.2, U2.12 (ISUM)
unnamed: C12.1, U2.14 (V3R3)
unnamed: C13.2, R11.2, U2.15 (V5)
unnamed: C14.2, R10.2, U2.16 (VIN)
unnamed: C4.2, C5.1, R3.2, U2.10 (VSN)
unnamed: C3.2, C4.1, R2.2, U2.9 (VSP)
unnamed: C27.1, U4.9 (BOOT)
unnamed: C27.2, U4.8 (BOOT_R)
unnamed: C22.1, R17.2, U4.3 (ENABLE), U4.5 (VDD)
unnamed: L2.1, R21.2, U4.6 (VSW)
unnamed: C28.1, U5.9 (BOOT)
unnamed: C28.2, U5.8 (BOOT_R)
unnamed: C24.1, R18.2, U5.3 (ENABLE), U5.5 (VDD)
unnamed: L3.1, R22.2, U5.6 (VSW)
unnamed: C29.1, U6.9 (BOOT)
unnamed: C29.2, U6.8 (BOOT_R)
unnamed: C25.1, R19.2, U6.3 (ENABLE), U6.5 (VDD)
unnamed: L4.1, R23.2, U6.6 (VSW)
unnamed: C30.1, U7.9 (BOOT)
unnamed: C30.2, U7.8 (BOOT_R)
unnamed: C26.1, R20.2, U7.3 (ENABLE), U7.5 (VDD)
unnamed: L5.1, R24.2, U7.6 (VSW)
VDD: C42.1, C45.1, C48.1, C49.1, C52.1, C53.1, C55.1, C58.1, C60.1, C63.1, C65.1, C67.1, C68.1, C70.1, C71.1, C73.1, C74.1, C77.1, C79.1, C81.1, C83.1, C86.1, C87.1, C89.1, C91.1, C92.1, J2.1, L2.2, L3.2, L4.2, L5.2, R25.2; also elsewhere on the board

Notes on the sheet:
100k = NVM
default Off
for IMAX=180A

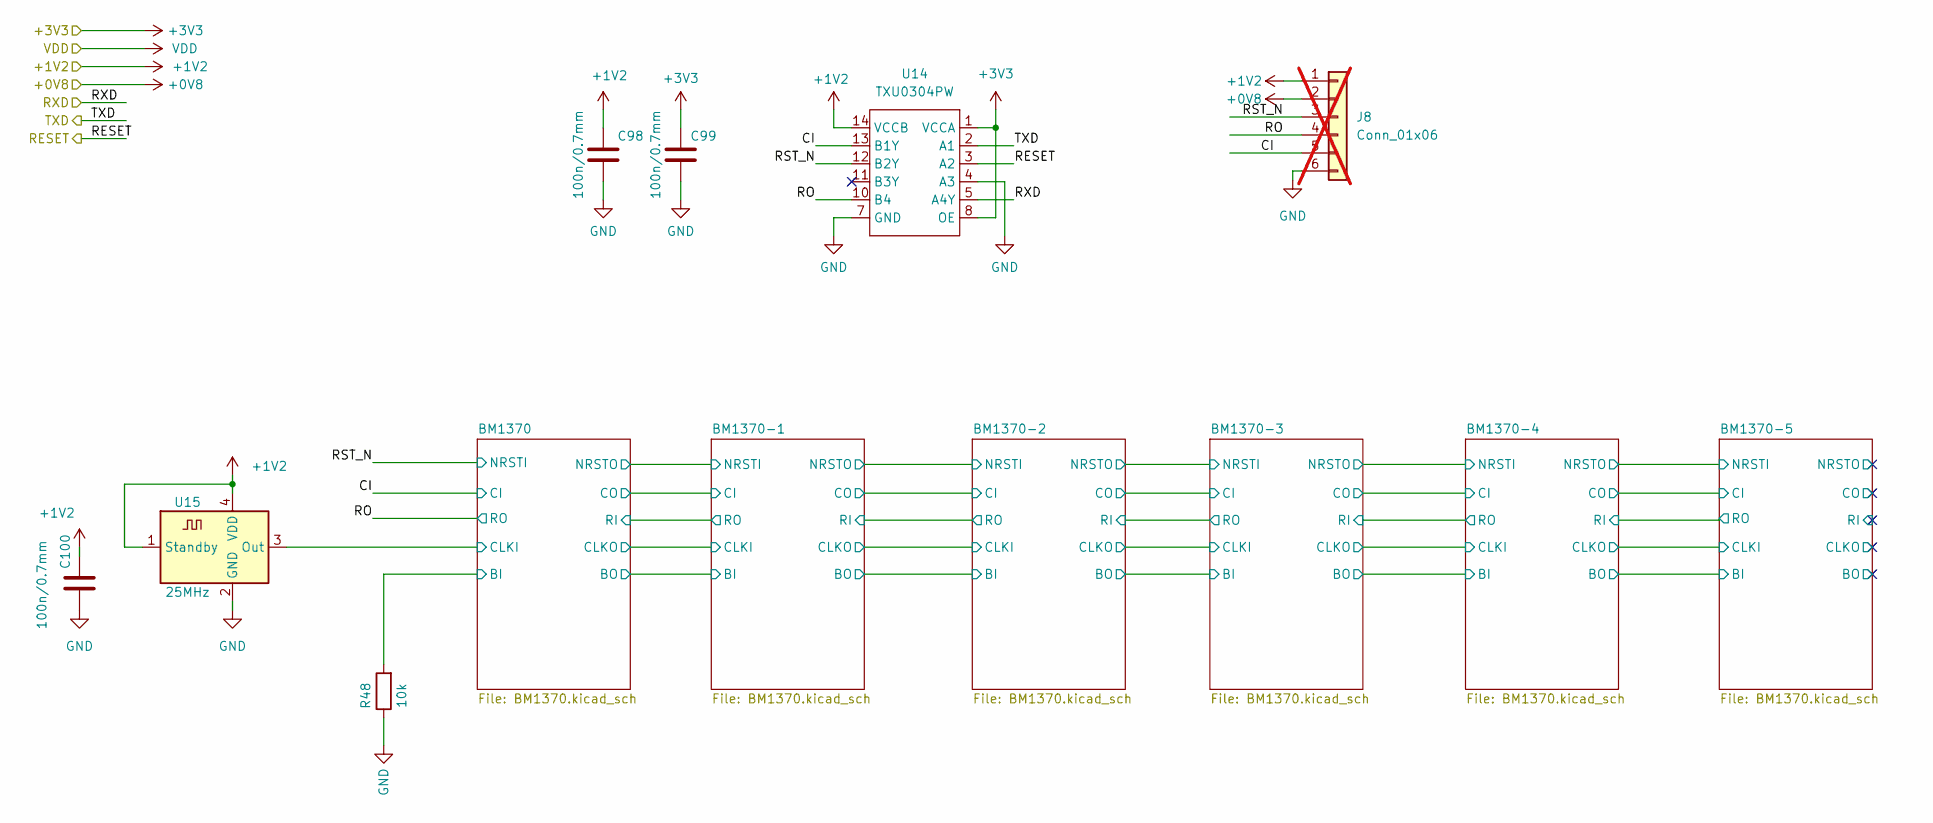
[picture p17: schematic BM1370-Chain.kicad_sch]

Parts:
C98, C99, C100: 100n/0.7mm; C_0805_2012Metric
J8: Conn_01x06; PinHeader_1x06_P1.27mm_Vertical; not fitted
R48: 10k; R_0805_2012Metric
U14: TXU0304PW; TSSOP-14-1EP_4.4x5mm_P0.65mm
U15: 25MHz; Oscillator_SMD_EuroQuartz_XO32-4Pin_3.2x2.5mm

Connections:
+0V8: J8.2; also elsewhere on the board
+1V2: C98.1, C100.1, J8.1, U14.14 (VCCB), U15.1 (Standby), U15.4 (VDD); also elsewhere on the board
+3V3: C99.1, U14.1 (VCCA), U14.8 (OE); also elsewhere on the board
/BM1370-Chain/BM1370/BI: R48.2; also elsewhere on the board
/BM1370-Chain/BM1370/CLKI: U15.3 (Out); also elsewhere on the board
/BM1370-Chain/CI: J8.5, U14.13 (B1Y); also elsewhere on the board
/BM1370-Chain/RESET: U14.3 (A2); also elsewhere on the board
/BM1370-Chain/RO: J8.4, U14.10 (B4); also elsewhere on the board
/BM1370-Chain/RST_N: J8.3, U14.12 (B2Y); also elsewhere on the board
/BM1370-Chain/RXD: U14.5 (A4Y); also elsewhere on the board
/BM1370-Chain/TXD: U14.2 (A1); also elsewhere on the board
GND: C98.2, C99.2, C100.2, J8.6, R48.1, U14.4 (A3), U14.7 (GND), U15.2 (GND); also elsewhere on the board

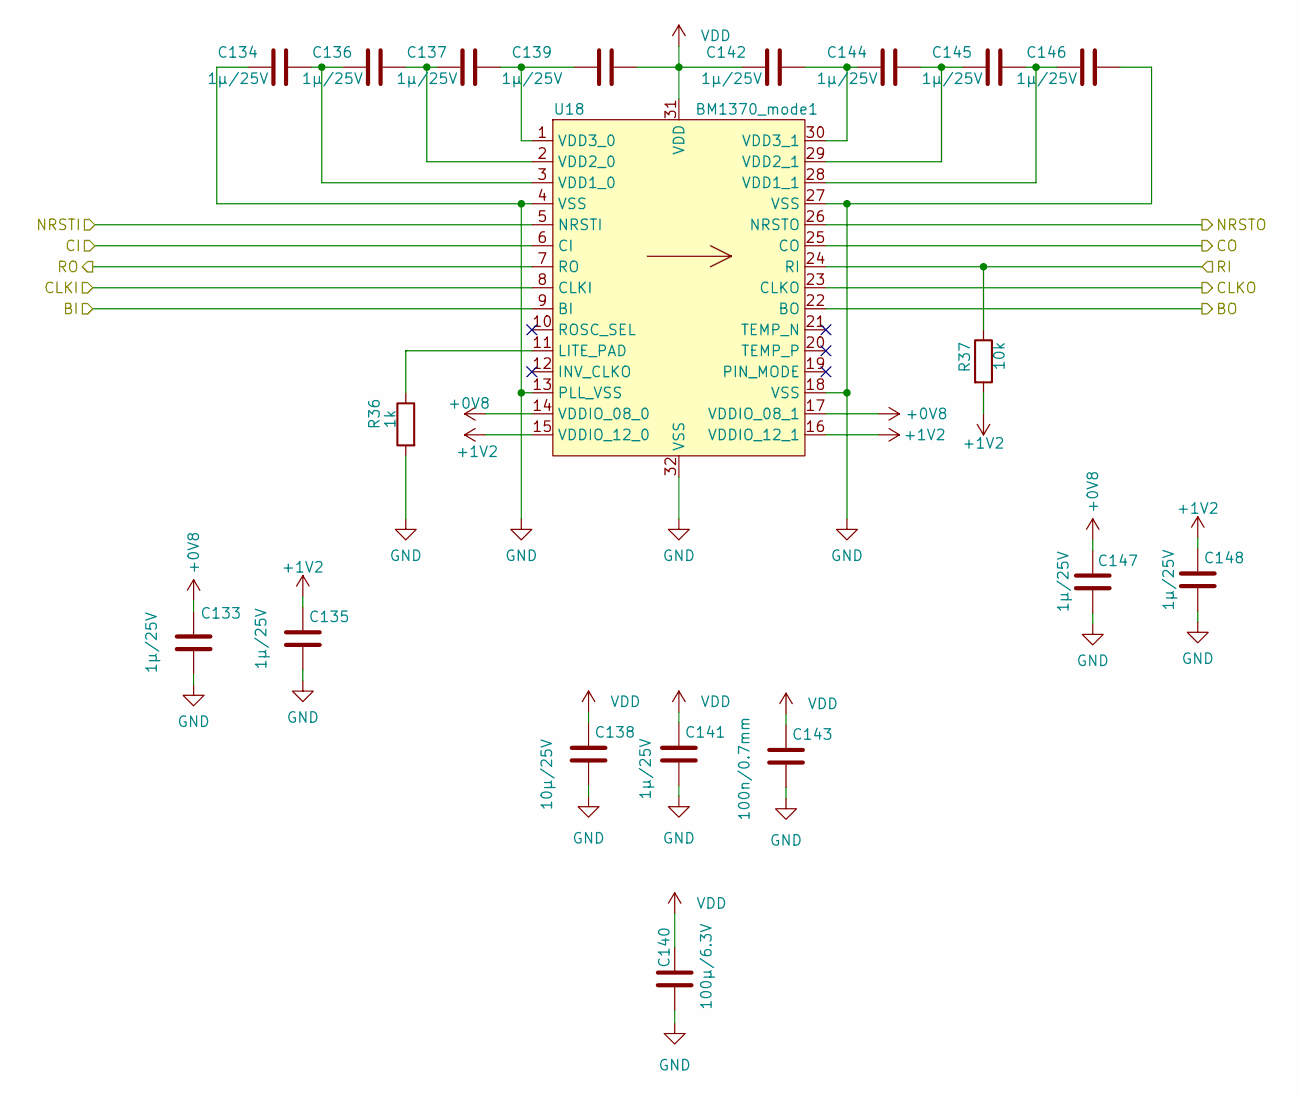
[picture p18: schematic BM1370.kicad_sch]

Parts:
C133, C134, C135, C136, C137, C139, C141, C142, C144, C145, C146, C147, C148: 1µ/25V; C_0805_2012Metric
C138: 10µ/25V; C_0805_2012Metric
C140: 100µ/6.3V; C_1210_3225Metric
C143: 100n/0.7mm; C_0805_2012Metric
R36: 1k; R_0805_2012Metric
R37: 10k; R_0805_2012Metric
U18: BM1370_mode1; BM1370

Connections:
+0V8: C133.2, C147.2, U18.14 (VDDIO_08_0), U18.17 (VDDIO_08_1); also elsewhere on the board
+1V2: C135.1, C148.1, R37.2, U18.15 (VDDIO_12_0), U18.16 (VDDIO_12_1); also elsewhere on the board
/BM1370-Chain/BM1370-1/BO: U18.9 (BI); also elsewhere on the board
/BM1370-Chain/BM1370-1/CLKO: U18.8 (CLKI); also elsewhere on the board
/BM1370-Chain/BM1370-1/CO: U18.6 (CI); also elsewhere on the board
/BM1370-Chain/BM1370-1/NRSTO: U18.5 (NRSTI); also elsewhere on the board
/BM1370-Chain/BM1370-1/RI: U18.7 (RO); also elsewhere on the board
/BM1370-Chain/BM1370-2/BO: U18.22 (BO); also elsewhere on the board
/BM1370-Chain/BM1370-2/CLKO: U18.23 (CLKO); also elsewhere on the board
/BM1370-Chain/BM1370-2/CO: U18.25 (CO); also elsewhere on the board
/BM1370-Chain/BM1370-2/NRSTO: U18.26 (NRSTO); also elsewhere on the board
/BM1370-Chain/BM1370-2/RI: R37.1, U18.24 (RI); also elsewhere on the board
GND: C133.1, C134.1, C135.2, C138.2, C140.2, C141.2, C143.2, C146.2, C147.1, C148.2, R36.2, U18.4 (VSS), U18.13 (PLL_VSS), U18.18 (VSS), U18.27 (VSS), U18.32 (VSS); also elsewhere on the board
unnamed: R36.1, U18.11 (LITE_PAD)
unnamed: C134.2, C136.1, U18.3 (VDD1_0)
unnamed: C145.2, C146.1, U18.28 (VDD1_1)
unnamed: C136.2, C137.1, U18.2 (VDD2_0)
unnamed: C144.2, C145.1, U18.29 (VDD2_1)
unnamed: C137.2, C139.1, U18.1 (VDD3_0)
unnamed: C142.2, C144.1, U18.30 (VDD3_1)
VDD: C138.1, C139.2, C140.1, C141.1, C142.1, C143.1, U18.31 (VDD); also elsewhere on the board

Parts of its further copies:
C101, C102, C103, C104, C105, C106, C107, C108, C109, C110, C111, C112, C114, C117, C118, C119, C120, C121, C123, C125, C126, C128, C129, C130, C131, C132, C149, C150, C151, C152, C153, C155, C157, C158, C160, C161, C162, C163, C164, C165, C166, C167, C168, C169, C171, C173, C174, C176, C177, C178, C179, C180, C181, C182, C183, C184, C185, C187, C189, C190, C192, C193, C194, C195, C196: 1µ/25V; C_0805_2012Metric
C113, C122, C154, C170, C186: 10µ/25V; C_0805_2012Metric
C115, C127, C159, C175, C191: 100n/0.7mm; C_0805_2012Metric
C116, C124, C156, C172, C188: 100µ/6.3V; C_1210_3225Metric
R30, R33, R39, R42, R45: 1k; R_0805_2012Metric
R31, R34, R40, R43, R46: 10k; R_0805_2012Metric
U16, U17, U19, U20, U21: BM1370_mode1; BM1370

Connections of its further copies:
+0V8: C109.2, C110.2, C117.2, C131.2, C149.2, C163.2, C165.2, C179.2, C181.2, C195.2, U16.14 (VDDIO_08_0), U16.17 (VDDIO_08_1), U17.14 (VDDIO_08_0), U17.17 (VDDIO_08_1), U19.14 (VDDIO_08_0), U19.17 (VDDIO_08_1), U20.14 (VDDIO_08_0), U20.17 (VDDIO_08_1), U21.14 (VDDIO_08_0), U21.17 (VDDIO_08_1); also elsewhere on the board
+1V2: C111.1, C112.1, C119.1, C132.1, C151.1, C164.1, C167.1, C180.1, C183.1, C196.1, R31.2, R34.2, R40.2, R43.2, R46.2, U16.15 (VDDIO_12_0), U16.16 (VDDIO_12_1), U17.15 (VDDIO_12_0), U17.16 (VDDIO_12_1), U19.15 (VDDIO_12_0), U19.16 (VDDIO_12_1), U20.15 (VDDIO_12_0), U20.16 (VDDIO_12_1), U21.15 (VDDIO_12_0), U21.16 (VDDIO_12_1); also elsewhere on the board
/BM1370-Chain/BM1370-1/BI: U16.22 (BO), U17.9 (BI)
/BM1370-Chain/BM1370-1/BO: U17.22 (BO); also elsewhere on the board
/BM1370-Chain/BM1370-1/CI: U16.25 (CO), U17.6 (CI)
/BM1370-Chain/BM1370-1/CLKI: U16.23 (CLKO), U17.8 (CLKI)
/BM1370-Chain/BM1370-1/CLKO: U17.23 (CLKO); also elsewhere on the board
/BM1370-Chain/BM1370-1/CO: U17.25 (CO); also elsewhere on the board
/BM1370-Chain/BM1370-1/NRSTI: U16.26 (NRSTO), U17.5 (NRSTI)
/BM1370-Chain/BM1370-1/NRSTO: U17.26 (NRSTO); also elsewhere on the board
/BM1370-Chain/BM1370-1/RI: R34.1, U17.24 (RI); also elsewhere on the board
/BM1370-Chain/BM1370-1/RO: R31.1, U16.24 (RI), U17.7 (RO)
/BM1370-Chain/BM1370-2/BO: U19.9 (BI); also elsewhere on the board
/BM1370-Chain/BM1370-2/CLKO: U19.8 (CLKI); also elsewhere on the board
/BM1370-Chain/BM1370-2/CO: U19.6 (CI); also elsewhere on the board
/BM1370-Chain/BM1370-2/NRSTO: U19.5 (NRSTI); also elsewhere on the board
/BM1370-Chain/BM1370-2/RI: U19.7 (RO); also elsewhere on the board
/BM1370-Chain/BM1370-3/BO: U19.22 (BO), U20.9 (BI)
/BM1370-Chain/BM1370-3/CLKO: U19.23 (CLKO), U20.8 (CLKI)
/BM1370-Chain/BM1370-3/CO: U19.25 (CO), U20.6 (CI)
/BM1370-Chain/BM1370-3/NRSTO: U19.26 (NRSTO), U20.5 (NRSTI)
/BM1370-Chain/BM1370-3/RI: R40.1, U19.24 (RI), U20.7 (RO)
/BM1370-Chain/BM1370-4/BO: U20.22 (BO), U21.9 (BI)
/BM1370-Chain/BM1370-4/CLKO: U20.23 (CLKO), U21.8 (CLKI)
/BM1370-Chain/BM1370-4/CO: U20.25 (CO), U21.6 (CI)
/BM1370-Chain/BM1370-4/NRSTO: U20.26 (NRSTO), U21.5 (NRSTI)
/BM1370-Chain/BM1370-4/RI: R43.1, U20.24 (RI), U21.7 (RO)
/BM1370-Chain/BM1370-5/BO: U21.22 (BO)
/BM1370-Chain/BM1370-5/CLKO: U21.23 (CLKO)
/BM1370-Chain/BM1370-5/CO: U21.25 (CO)
/BM1370-Chain/BM1370-5/NRSTO: U21.26 (NRSTO)
/BM1370-Chain/BM1370-5/RI: R46.1, U21.24 (RI)
/BM1370-Chain/BM1370/BI: U16.9 (BI); also elsewhere on the board
/BM1370-Chain/BM1370/CLKI: U16.8 (CLKI); also elsewhere on the board
/BM1370-Chain/CI: U16.6 (CI); also elsewhere on the board
/BM1370-Chain/RO: U16.7 (RO); also elsewhere on the board
/BM1370-Chain/RST_N: U16.5 (NRSTI); also elsewhere on the board
GND: C101.1, C108.2, C109.1, C110.1, C111.2, C112.2, C113.2, C114.2, C115.2, C116.2, C117.1, C118.1, C119.2, C122.2, C124.2, C125.2, C127.2, C130.2, C131.1, C132.2, C149.1, C150.1, C151.2, C154.2, C156.2, C157.2, C159.2, C162.2, C163.1, C164.2, C165.1, C166.1, C167.2, C170.2, C172.2, C173.2, C175.2, C178.2, C179.1, C180.2, C181.1, C182.1, C183.2, C186.2, C188.2, C189.2, C191.2, C194.2, C195.1, C196.2, R30.2, R33.2, R39.2, R42.2, R45.2, U16.4 (VSS), U16.13 (PLL_VSS), U16.18 (VSS), U16.27 (VSS), U16.32 (VSS), U17.4 (VSS), U17.13 (PLL_VSS), U17.18 (VSS), U17.27 (VSS), U17.32 (VSS), U19.4 (VSS), U19.13 (PLL_VSS), U19.18 (VSS), U19.27 (VSS), U19.32 (VSS), U20.4 (VSS), U20.13 (PLL_VSS), U20.18 (VSS), U20.27 (VSS), U20.32 (VSS), U21.4 (VSS), U21.13 (PLL_VSS), U21.18 (VSS), U21.27 (VSS), U21.32 (VSS); also elsewhere on the board
unnamed: R30.1, U16.11 (LITE_PAD)
unnamed: C101.2, C102.1, U16.3 (VDD1_0)
unnamed: C107.2, C108.1, U16.28 (VDD1_1)
unnamed: C102.2, C103.1, U16.2 (VDD2_0)
unnamed: C106.2, C107.1, U16.29 (VDD2_1)
unnamed: C103.2, C104.1, U16.1 (VDD3_0)
unnamed: C105.2, C106.1, U16.30 (VDD3_1)
unnamed: R33.1, U17.11 (LITE_PAD)
unnamed: C118.2, C120.1, U17.3 (VDD1_0)
unnamed: C129.2, C130.1, U17.28 (VDD1_1)
unnamed: C120.2, C121.1, U17.2 (VDD2_0)
unnamed: C128.2, C129.1, U17.29 (VDD2_1)
unnamed: C121.2, C123.1, U17.1 (VDD3_0)
unnamed: C126.2, C128.1, U17.30 (VDD3_1)
unnamed: R39.1, U19.11 (LITE_PAD)
unnamed: C150.2, C152.1, U19.3 (VDD1_0)
unnamed: C161.2, C162.1, U19.28 (VDD1_1)
unnamed: C152.2, C153.1, U19.2 (VDD2_0)
unnamed: C160.2, C161.1, U19.29 (VDD2_1)
unnamed: C153.2, C155.1, U19.1 (VDD3_0)
unnamed: C158.2, C160.1, U19.30 (VDD3_1)
unnamed: R42.1, U20.11 (LITE_PAD)
unnamed: C166.2, C168.1, U20.3 (VDD1_0)
unnamed: C177.2, C178.1, U20.28 (VDD1_1)
unnamed: C168.2, C169.1, U20.2 (VDD2_0)
unnamed: C176.2, C177.1, U20.29 (VDD2_1)
unnamed: C169.2, C171.1, U20.1 (VDD3_0)
unnamed: C174.2, C176.1, U20.30 (VDD3_1)
unnamed: R45.1, U21.11 (LITE_PAD)
unnamed: C182.2, C184.1, U21.3 (VDD1_0)
unnamed: C193.2, C194.1, U21.28 (VDD1_1)
unnamed: C184.2, C185.1, U21.2 (VDD2_0)
unnamed: C192.2, C193.1, U21.29 (VDD2_1)
unnamed: C185.2, C187.1, U21.1 (VDD3_0)
unnamed: C190.2, C192.1, U21.30 (VDD3_1)
VDD: C104.2, C105.1, C113.1, C114.1, C115.1, C116.1, C122.1, C123.2, C124.1, C125.1, C126.1, C127.1, C154.1, C155.2, C156.1, C157.1, C158.1, C159.1, C170.1, C171.2, C172.1, C173.1, C174.1, C175.1, C186.1, C187.2, C188.1, C189.1, C190.1, C191.1, U16.31 (VDD), U17.31 (VDD), U19.31 (VDD), U20.31 (VDD), U21.31 (VDD); also elsewhere on the board

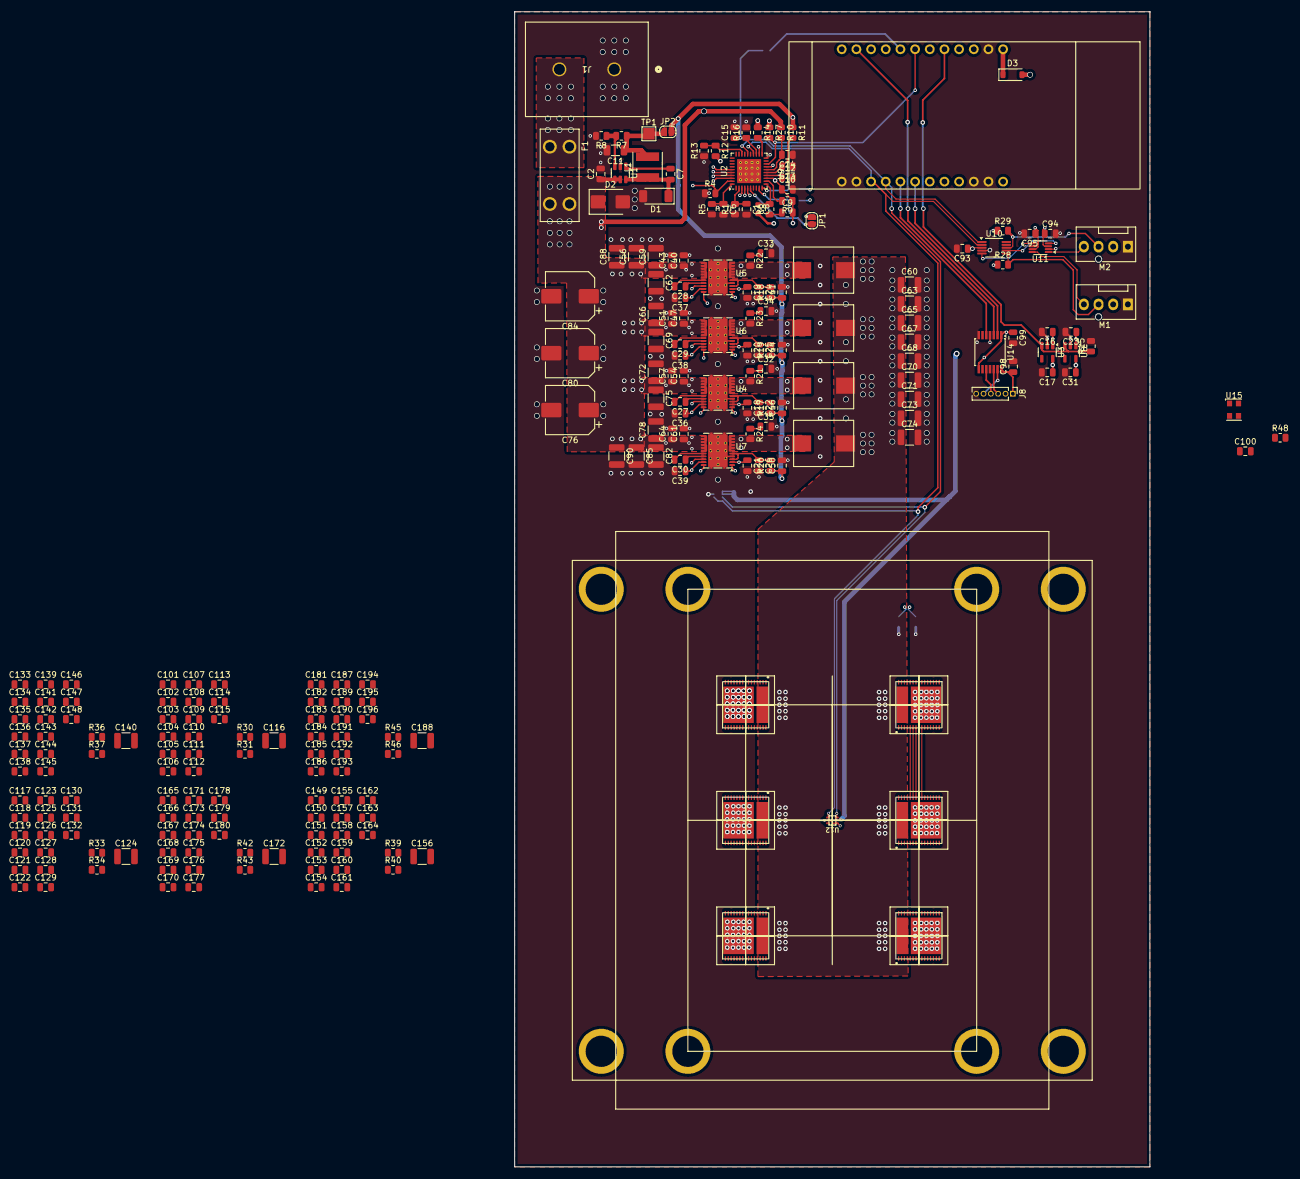
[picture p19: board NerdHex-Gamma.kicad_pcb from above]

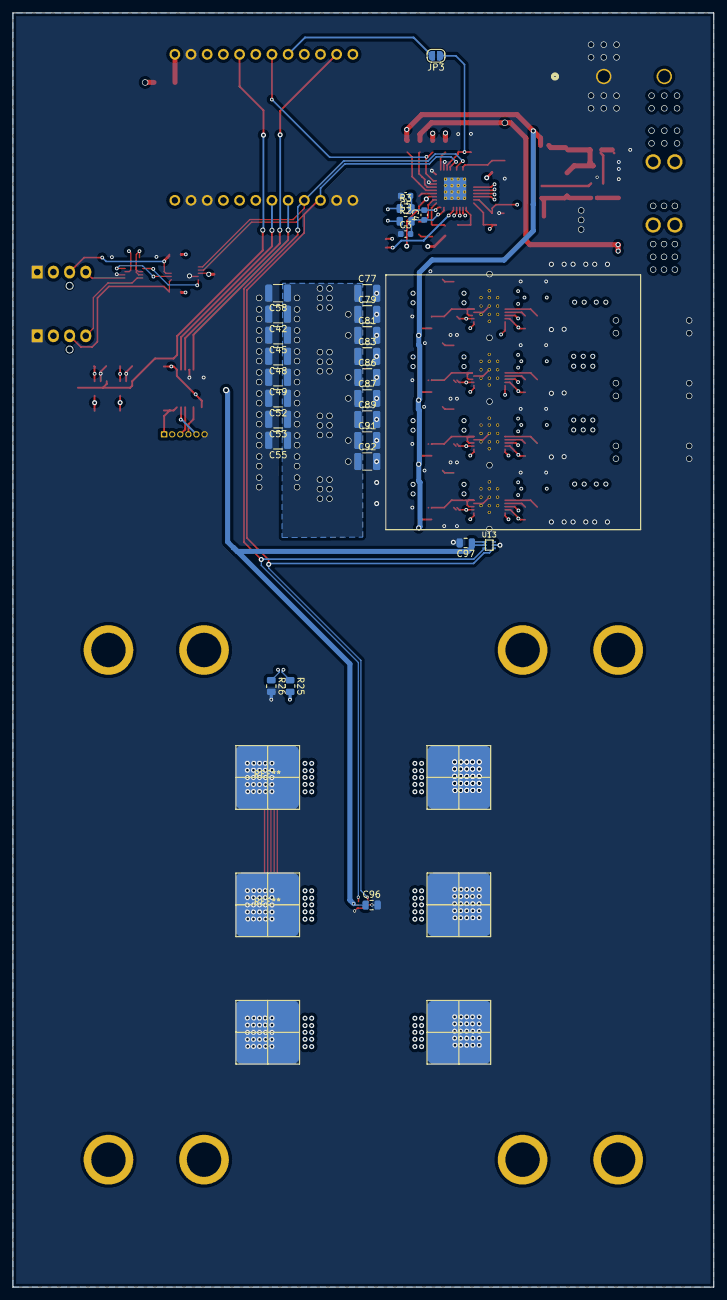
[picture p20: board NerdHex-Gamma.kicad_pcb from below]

Board: 6 copper layers, 110.0 x 200.0 mm, 276 parts (28 on the bottom side), 145 nets.

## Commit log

2025-01-23 plated slots
2025-02-23 DK Bom
    [HaxeBom.csv, HaxeBom_DK.csv, HaxeBom_Digi.csv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]
